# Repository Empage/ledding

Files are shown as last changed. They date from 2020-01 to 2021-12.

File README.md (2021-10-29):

Ledding
=======

Fancy LED project

<!-- vim-markdown-toc GFM -->

* [Hardware](#hardware)
    * [LED stripe WS2812B and WS2815](#led-stripe-ws2812b-and-ws2815)
        * [Timing:](#timing)
    * [Power considerations](#power-considerations)
        * [WS2812B](#ws2812b)
        * [WS2815](#ws2815)
        * [Cabling](#cabling)
    * [Level shifters](#level-shifters)
* [Software](#software)
    * [Installation](#installation)
    * [Important commands](#important-commands)
    * [Programming](#programming)
    * [Debugging using JTAG](#debugging-using-jtag)
        * [Make the physical connection](#make-the-physical-connection)
        * [One time setup configuration](#one-time-setup-configuration)
        * [Start a debugging session](#start-a-debugging-session)
* [Specifics for Partyraum Installation](#specifics-for-partyraum-installation)
    * [I/O](#io)
* [Specifics for Maite Installation](#specifics-for-maite-installation)
    * [Box interfaces](#box-interfaces)
    * [Buttons](#buttons)
* [TODO](#todo)
* [Lessons learned](#lessons-learned)

<!-- vim-markdown-toc -->

## Hardware
1. MCU is the ESP32

Feature | Description
---------- | ------
SoM | from Broodio (quite unknown, selecting the ESP32 Development Kit (DevKitC) is suitable)
SoC | ESP-WROOM-32D
CPU | ESP32-D0WD
Flash | 4 MiB
RAM | 320 KiB

1. LED stripes are WS2812B and WS2815 with 30 LEDs per meter and WS2812B with 60 LEDs per meter.

### LED stripe WS2812B and WS2815
Consists of a 5050 SMD and a WS2812B or WS2815 chip.

#### Timing:
Clock of the stripe is at 800 kHz. Writing one bit takes
```
t_b = 1 / 800 kHz = 1.25 µs
```
Writing one pixel takes
```
t_B = 24 bit * 1.25 µs/bit = 30 µs`
```
Writing 10m stripe of 30 LED/m takes
```
T = 10 m * 30 px/m * 30 µs = 9 ms
```
This would give a maximum refresh rate of
```
f = 1 / 9 ms ≈ 111 Hz
```

### Power considerations
#### WS2812B
For the 5V strips each LED pulls max. ~20 mA (realistic max is 15 mA) per color, so 60 mA (45 mA) per pixel.
For 10 m of the 30 px/m stripe, we have at maximum brightness
```
Theoretical:
I_t5 = 10 m * 30 px/m * 60 mA/px = 18 A
P_t5 = 18 A * 5V = 90 W

Realistic:
I_r5 = 10 m * 30 px/m * 45 mA/px = 13.5 A
P_r5 = 13.5 A * 5V = 67.5 W
```

#### WS2815
For the 12V strips each LED pulls max. 15 mA per color, but also max. 15 mA for the full pixel (they are in series). Power is burnt for non-white.
For 10 m of the 30 LED/m stripe, we have at maximum brightness
```
I_r12 = 10 m * 30 px/m * 15 mA/px = 4.5 A
P_r12 = 15 A * 12V = 54 W
```

#### Cabling
For the cable the resistance is
```
R = l / (\kappa * A)
```
where l is the cable length in m, kappa is the conductivity in (m / (\ohm * mm^2)) and A is the cross-section in mm^2.
Longest length is 18 m (twice that to account for GND back) with copper `\gamma = 57.18 (m / (\ohm * mm^2))`
```
R_2.5 = 36 m / 57.18 (m / (\ohm * mm^2)) / 2.5 mm^2 ≈ 0.252 \Ohm
R_1.5 = 36 m / 57.18 (m / (\ohm * mm^2)) / 1.5 mm^2 ≈ 0.420 \Ohm
```
Assuming to power 5 m of the LED strip with the 18m of cable leads to
```
I = 5 m * 30 px/m * 45 mA = 6.75 A
U = 0.252 * 6.75 A = 1.701 V
```
leaving only `5 - 1.701 = 3.299 V` for the LEDs with 2.5 mm^2 copper cable. Not really enough...\
With the WS2815 it would be:
```
I = 5 m * 30px/m * 15 mA = 2.25 A
U_c2.5 = 0.252 * 2.25 A = 0.567 V for 2.5 mm^2 copper or
U_c1.5 = 0.420 * 2.25 A = 0.945 V for 1.5 mm^2 copper
```
leaving > 11 V for the LEDs in both cases. This should enough for equal color rendering on all LEDs (to be confirmed).

### Level shifters
Available (should be fast enough):
- 74AHCT125 (quad level shifter)
- TXB0108 (eight channel bi-directional)

## Software
### Installation
This project uses platformio (https://platformio.org/) as its build system.
To install platformio, download and execute the `get-plaformio.py` script
```
wget https://raw.githubusercontent.com/platformio/platformio-core-installer/master/get-platformio.py -O get-platformio.py
python3 get-platformio.py
```

Install dependencies with pio:

```
pio lib install "FastLED"
```

To be able to upload, the user needs to be able to open the USB device, thus being in the `dialout` group
```
sudo usermod -aG dialout <user>
```

### Important commands
Important platformio commands (next to those in the Makefile which are described there):

Start serial console:
```
pio device monitor -b 115200
```

Generate `compile_commands.json`:
```
platformio run --target compiledb
mv .pio/build/ota/compile_commands.json .
```

### Programming
Important configuration is passed via environment variables (such as WLAN_SSID, PSK and IPs).
To work with a specific enviroment, we can source the relevant enviroment:
```
source env-partyraum
```
After that, we can use the Makefile targets for programming:
- To program the ESP32 via USB cable, issue `make upload`, then hold down the `BOOT` button on the ESP32-board until the upload starts.
- For OTA programming, issue `make ota`

The `env-partyraum` is the default environment and doesn't need to be sourced, but we can use this file to create custom
environments such as `env-maite` or `env-testbed` (not commited due to secret WLAN PSK).

### Debugging using JTAG
On-target debugging with GDB is possible using JTAG. I have the `FT4232H-56Q MiniModule` as the USB2JTAG adapter. The following steps are necessary:

#### Make the physical connection
| JTAG function | ESP32 pin | FT4232H pin |
| --- | --- | --- |
| TDI (Test Data In) | GPIO12 | AD1 |
| TDO (Test Data Out) | GPIO15 | AD2 |
| TCK (Test Clock) | GPIO13 | AD0 |
| TMS (Test Mode Select) | GPIO14 | AD3 |
| TRST (Test Reset) | EN | RT# |
| GND | GND | GND |

Furthermore the jumpers on the MiniModule need to be set to provide the reference voltage.

#### One time setup configuration
This module is not recognized correctly by `OpenOCD` (Open On-Chip-Debugger) used by `platformio` which is why
we need to tell it. Connect the MiniModule to USB and get the description and IDs:
```
$ pio device list

/dev/ttyUSB3
------------
Hardware ID: USB VID:PID=0403:6011 SER=FT2AWE2C LOCATION=1-5:1.3
Description: FT4232H-56Q MiniModule

/dev/ttyUSB2
------------
Hardware ID: USB VID:PID=0403:6011 SER=FT2AWE2C LOCATION=1-5:1.2
Description: FT4232H-56Q MiniModule

/dev/ttyUSB1
------------
Hardware ID: USB VID:PID=0403:6011 SER=FT2AWE2C LOCATION=1-5:1.1
Description: FT4232H-56Q MiniModule

/dev/ttyUSB0
------------
Hardware ID: USB VID:PID=0403:6011 SER=FT2AWE2C LOCATION=1-5:1.0
Description: FT4232H-56Q MiniModule
```

For this module, we need to add (or change the existing values) in `~/.platformio/packages/tool-openocd-esp32/share/openocd/scripts/interface/ftdi/minimodule.cfg`
Add or change the following:
```
ftdi_device_desc "FT4232H-56Q MiniModule"
ftdi_vid_pid 0x0403 0x6011
```

This should eliminate the following errors on a debug run
```
$ pio debug --interface gdb -x .pioinit

[...]
Error: no device found
Error: unable to open ftdi device with vid 0403, pid 6011, description 'FT2232H MiniModule', serial '*' at bus location '*'
```

This is valid for the `debug_tool = minimodule` (see `platformio.ini`).
We would only need to repeat those steps if the `platformio` update replaced this files with the originals again.

#### Start a debugging session
**Potential pitfall first**:
The GPIOs for JTAG (12 - 15) are also used for touch buttons. When they are actually used for this functionality,
the debugger cannot initiate the debugging session.
TODO add error msg here

That's why we must flash a firmware not using those buttons first using the normal flashing mechanisms. It can basically be any firmware because during beginning of the JTAG session the firmware to be debugged will be loaded anyway.

Building a debug version of the firmware will define `DEBUG_JTAG` and hence not use those touch buttons, so `make debug` will work.

To actually start a debugging session with GDB, use
```
pio debug --interface gdb -x .pioinit
```

## Specifics for Partyraum Installation
LED stripes of
- 2x 10 m
- 4x  2 m

results in `28 m * 30 px/m = 840 px`. Safety margin: `900 px`

We choose the WS2815 for less current and therefore easier cabeling
Theoretically, we need
```
900 px * 15 mA/px = 13.5 A
13.5 A * 12 V = 162 W
```

The Meanwell LRS-200-12 is a good fit.

### I/O

- Button 1: Brightness
- Button 2: Mode
- Button 3: Color
- Button 4: Intensity
- LED 1: WiFi connected?
- LED 2: Serial data from Raspberry Pi received last second
- LED 3: TODO
- LED 4: TODO

## Specifics for Maite Installation
LED stripes WS2812B
```
5 m * 30 px/m = 150 px
```
Power consumption (realistic maximum)
```
I_r5 = 5 m * 30 px/m * 45 mA/px = 6.75 A
P_r5 = 6.75 A * 5V = 33.75 W
```

Cable is J-Y(ST)Y:
```
R_0.6 = 12 m / 57.18 (m / (\ohm * mm^2)) / 0.6 mm^2 ≈ 0.350 \Ohm
R_1.2 = 12 m / 57.18 (m / (\ohm * mm^2)) / 1.2 mm^2 ≈ 0.175 \Ohm
```
Assuming to power half of the LED strip:
```
I = 2.5 m * 30 px/m * 45 mA = 3.375 A
U_0.6 = 0.350 * 3.375 A = 1.181 V
U_1.2 = 0.175 * 3.375 A = 0.591 V
```

### Box interfaces
- Power Input
- µUSB
- Led OUT 5-port:
    - Data
    - GND front
    - VCC front
    - GND back
    - VCC back
- Status LED
- 3 Buttons
- Power switch
- 2 Potis for speed and brightness

### Buttons
1. Brightness +
2. Brightness -
3. Speed +
4. Speed -
5. Color next
6. Color prev
7. Mode next
8. Mode prev

## TODO
1. Add schematics
    1. Add a RPI connection to the `BOOT` button to be able to flash without manual interaction
1. Use ESP Log functions instead of serial directly for more finegrained logging

## Lessons learned
1. When creating a new environment in `platformio.ini`, one needs to reinstall the dependency libraries

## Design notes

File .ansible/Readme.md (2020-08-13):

This is design for the use on the raspberry, but it can be used from remote machines aswell.
All you have to do would be editing the hosts-file.

Use "make build" for installing prerequisite.

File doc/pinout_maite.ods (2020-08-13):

 |  | ESP32
Case Plug |  | Antenna
5V |  | EN | GPIO23 | B1 Level Shifter (Stripe Data)
GND |  | GPIO36 | GPIO22
Status LED |  | GPIO39 | GPIO1
Stripe Data |  | GPIO34 | GPIO3
 |  | GPIO35 | GPIO21
 | T9: Color next | GPIO32 | GPIO19
 | T8: Color prev | GPIO33 | GPIO18 | DevButton
 |  | GPIO25 | GPIO5
 |  | GPIO26 | GPIO17
 | T7: Brightness - | GPIO27 | GPIO16
 | T6: Brightness + | GPIO14 | GPIO4 | T0: Mode prev
 | T5: Intensity - | GPIO12 | GPIO2 | Internal Blue LED
 | T4: Intensity + | GPIO13 | GPIO15 | T3: Mode next
 |  | GND | GND
 | 5V | VIN | 3V3
 |  | USB
 |  | SN74HCT245
 |  | Notch
 | GND | DIR | Vcc | 5V
 | Stripe Data | A1 | OE | GND
 |  | A2 | B1 | GPIO23
 |  | A3 | B2
 |  | A4 | B3
 |  | A5 | B4
 |  | A6 | B5
 |  | A7 | B6
 |  | A8 | B7
 | GND | GND | B8
 |  | Button Layout
 |  | Brightness + | Mode next | Color next | Intensity +
 |  | Brightness - | Mode prev | Color prev | Intensity -

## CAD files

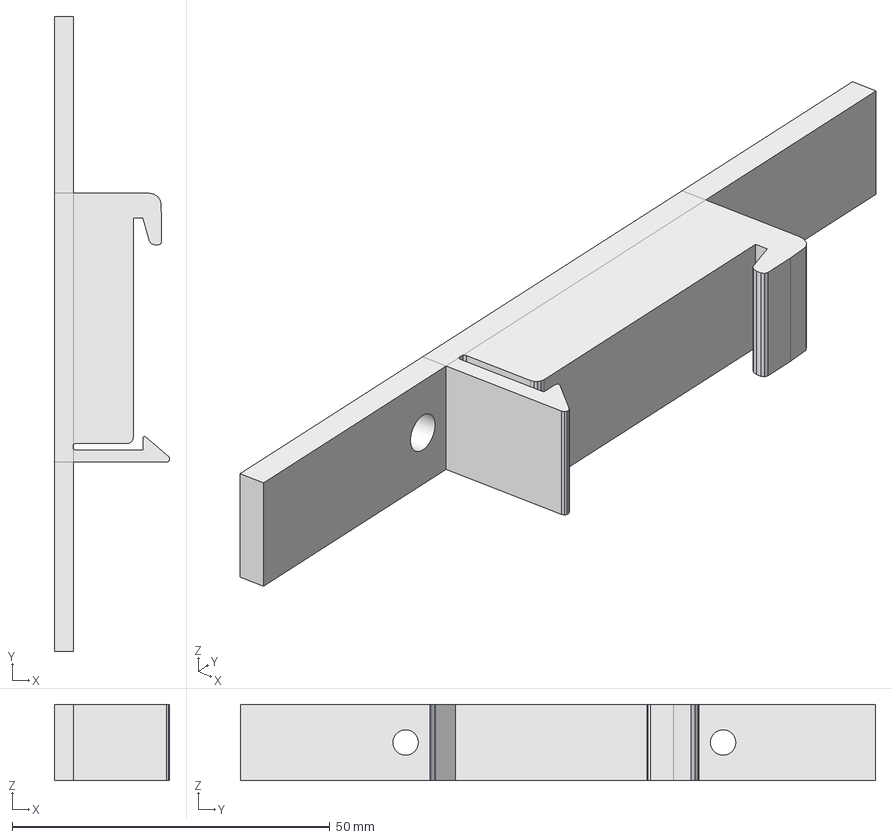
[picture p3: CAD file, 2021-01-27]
doc/3dprinting/dinrail_mw_lrs200.FCStd
18.2 x 100.0 x 12.0 mm

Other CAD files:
doc/3dprinting/dinrail_mw_lrs200.stl

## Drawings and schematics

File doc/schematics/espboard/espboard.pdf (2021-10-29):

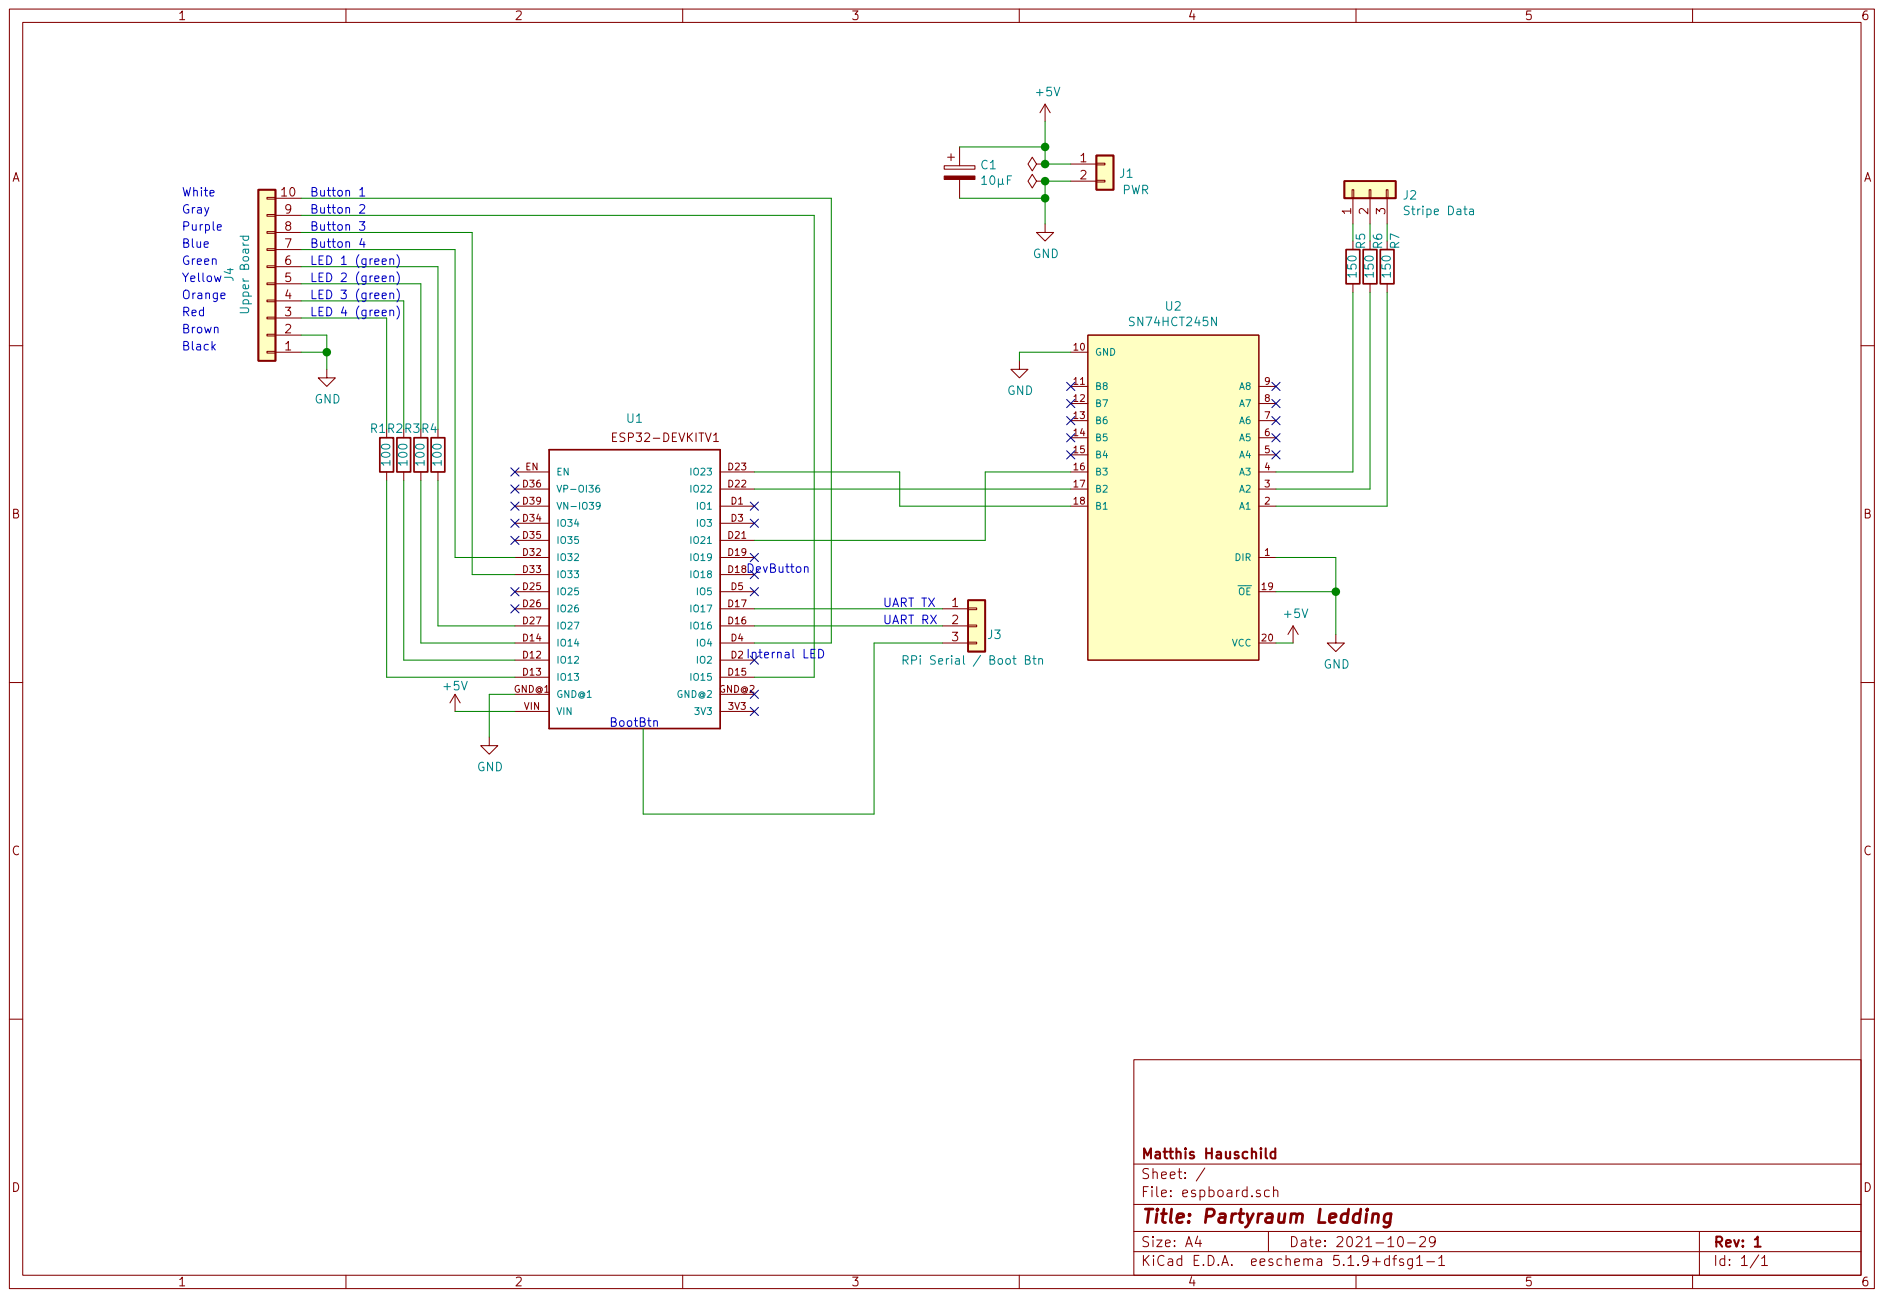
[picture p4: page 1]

LED 3 (green) Button 3 Button 4

File: espboard.sch Sheet: / Matthis Hauschild

Id: 1/1 Title: Partyraum Ledding

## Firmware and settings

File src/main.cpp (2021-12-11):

/* Ledding - a fancy LED project */

#include <Arduino.h>
#include <FastLED.h>
#include <config.h>

/* include global instances of leds, animator, buttons, ota and effects */
#include "globals.h"

void setupMaite() {
	animator.mode = Animator::ANIMATOR_CONSTANT;
}

void setupThias() {
	animator.mode = Animator::ANIMATOR_CONSTANT;
}

#ifdef CONF_PARTYRAUM
void setupPartyraum() {
	/* setup connection to RPi */
    Serial2.begin(115200, SERIAL_8N1, SERIAL_TO_RPI_RXD2, SERIAL_TO_RPI_TXD2);

	/* setup partyraum specifc effects */
	arcEffect.configure(CRGB::Blue, CRGB::Green);
	animator.addEffect(Animator::ANIMATOR_ARC, &arcEffect);
	soundEffect.configure(CRGB::Red);
	animator.addEffect(Animator::ANIMATOR_SOUND, &soundEffect);

	animator.mode = Animator::ANIMATOR_SOUND;

	pinMode(STATUS_LED_1, OUTPUT);
	pinMode(STATUS_LED_2, OUTPUT);
	pinMode(STATUS_LED_3, OUTPUT);
	pinMode(STATUS_LED_4, OUTPUT);

	digitalWrite(STATUS_LED_1, LOW);
	digitalWrite(STATUS_LED_2, LOW);
	digitalWrite(STATUS_LED_3, LOW);
	digitalWrite(STATUS_LED_4, LOW);
}
#endif /* CONF_PARTYRAUM */

void setup() {
	FastLED.addLeds<WS2812B, LED_DATA_PIN, GRB>(leds, NUM_LEDS);
	FastLED.addLeds<WS2812B, LED_DATA_PIN2, GRB>(leds + NUM_LEDS, NUM_LEDS);
	FastLED.setBrightness(DEF_GLOBAL_BRIGHTNESS);
	FastLED.setDither();
    fill_solid(leds, NUM_LEDS, CRGB::Black);
    fill_solid(leds + NUM_LEDS, NUM_LEDS, CRGB::Red);
    FastLED.show();

	pinMode(BUILTIN_LED, OUTPUT);

#ifdef SERIAL_PRINT
	Serial.begin(115200);
#endif

	/* setup common effects */
	staticEffect.configure(CRGB::DeepPink);
	animator.addEffect(Animator::ANIMATOR_CONSTANT, &staticEffect);
	boltEffect.configure(0, 2, CRGB::Red, 10);
	animator.addEffect(Animator::ANIMATOR_BOLT, &boltEffect);
	strobeEffect.configure(CRGB::White);//, 3, 50, 1000);
	animator.addEffect(Animator::ANIMATOR_STROBE, &strobeEffect);
	sparkleEffect.configure(CRGB::White, true);
	animator.addEffect(Animator::ANIMATOR_SPARKLE, &sparkleEffect);
	meteorEffect.configure(CRGB::Blue);
	animator.addEffect(Animator::ANIMATOR_METEOR, &meteorEffect);

	/* setup specifics for individual installation */
#ifdef CONF_MAITE
	setupMaite();
#elif CONF_THIAS
	setupThias();
#elif CONF_PARTYRAUM
	setupPartyraum();
#endif

#ifdef DEV_MODE
	/* turn on builtin LED */
	digitalWrite(BUILTIN_LED, HIGH);
#endif

	ota.init();
}


void loop() {
	ota.handleOta();

	EVERY_N_MILLISECONDS(REDRAW_RESOLUTION) {
		animator.redraw();
	}

	EVERY_N_MILLISECONDS(BUTTON_CHECK_RES) {
		buttons.handleButtons();
	}
}

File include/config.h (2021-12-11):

#ifndef CONFIG_H
#define CONFIG_H

#include <IPAddress.h>
#include <FastLED.h>

/*! Configuration of the project
 *
 * All config parameters which are defined extern are located in `config.cpp`
 */

/*************************/
/* dynamic configuration */
/*************************/
/*! \brief Print all actions on serial */
#define SERIAL_PRINT

/*! \brief Activate developing mode, currently
 * - extra button on dev board
 */
#define DEV_MODE
#define DEV_BUTTON_PIN 18


/***********************************/
/* static configuration for all HW */
/***********************************/

/* WiFi and OTA settings set in config.cpp */
extern const char* SSID;
extern const char* WIFI_PSK;
extern const char* OTA_PW;

/* for pin configuration, please check doc/pinout_maite.ods */
/*! \brief GPIO on which the data signal of the WS2812B is connected */
#define LED_DATA_PIN 23
#define LED_DATA_PIN2 22

/*! \brief GPIO for the built-in LED */
#define BUILTIN_LED 2

/*! \brief How often are the button states polled in ms */
#define BUTTON_CHECK_RES 100

/*! \brief Resolution of the stripe redrawing routine (i.e. the delay each round) in ms */
#define REDRAW_RESOLUTION 10

/*! \brief Default global brightness to start with */
#define DEF_GLOBAL_BRIGHTNESS 200

extern const IPAddress OWN_IP_ADDRESS;
extern const IPAddress SUBNET;

extern const uint16_t OTA_PORT;

/*! \brief These colors are choseable by button */
extern const CRGB::HTMLColorCode COLOR_PALETTE[];
extern const int COLOR_PALETTE_SIZE;

/* tmp */
#define MIC_PIN 13
#define DC_OFFSET 0
#define SQUELCH 0



/******************************************/
/* static configuration for individual HW */
/******************************************/
#ifdef CONF_MAITE
	/*! \brief Total number of LEDs */
	#define NUM_LEDS 150
	#define HAS_TOUCHBUTTONS

#elif CONF_THIAS
	/*! \brief Total number of LEDs */
	#define NUM_LEDS 120
	#define HAS_TOUCHBUTTONS

#elif CONF_MATTHIS
	/*! \brief Total number of LEDs */
	#define NUM_LEDS 150

#elif CONF_PARTYRAUM
	/*! \brief Total number of LEDs */
	#define NUM_LEDS 480
	#define HAS_PD_BUTTONS

	/*! \brief Serial input from RPi (LED data) */
	#define SERIAL_TO_RPI_RXD2 17
	/*! \brief Serial output to RPi (ACKs for LED data input) */
	#define SERIAL_TO_RPI_TXD2 16

	#define STATUS_LED_1 27
	#define STATUS_LED_2 13
	#define STATUS_LED_3 12
	#define STATUS_LED_4 14

#else
	#error "Please define the HW for which to build"
#endif


#ifdef HAS_TOUCHBUTTONS
/*! \brief Touch button definitions
 *
 * Layout on Maites & Thias version:
 * BRT_INC   MODE_NEXT   COLOR_NEXT   INTENSITY_INC
 * BRT_DEC   MODE_NEXT   COLOR_PREV   INTENSITY_DEC
 *
 * If using JTAG, one cannot use the GPIOs linked to that for touch (12 - 15).
 * This will be handled in the Buttons class, here we only need to change the button count
 */
#ifdef DEBUG_JTAG
	#define TOUCH_BUTTON_COUNT    4
#else
	#define TOUCH_BUTTON_COUNT    8
#endif

#define BUTTON_BRT_INC       14
#define BUTTON_BRT_DEC       27
#define BUTTON_MODE_NEXT     15
#define BUTTON_MODE_PREV      4
#define BUTTON_COLOR_NEXT    33 /* this should be GPIO32 */
#define BUTTON_COLOR_PREV    32 /* this should be GPIO33, dont know where the mixup is */
#define BUTTON_INTENSITY_INC 13
#define BUTTON_INTENSITY_DEC 12

/*! \brief Threshold value of the touch button
 *
 * This is highly depenend on the concrete realization and should be tested in each device
 * If the actual value which was read was below this twice in a row, the button is considered pressed.
 * Twice because there a some occasional bogus reads below the threshold although it was not pressed.
 */
#define TOUCH_BUTTON_THRESHOLD 30

#endif /* HAS_TOUCHBUTTONS */

#ifdef HAS_PD_BUTTONS
	#define PD_BUTTON_COUNT       4

	#define BUTTON_BRT_INC        4
	#define BUTTON_MODE_NEXT     15
	#define BUTTON_COLOR_NEXT    33
	#define BUTTON_INTENSITY_INC 32
#endif  /* HAS_PD_BUTTONS */

#endif /* end of include guard: CONFIG_H */

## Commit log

2020-01-06 Initialized the project
    Using `platformio init --ide vim --board esp32dev`
2020-05-16 Add some theory and datasheets
    [price_analysis.ods]
2020-07-29 Make a first test version practical with:
    - touch buttons
    - ArduinoOTA
    - event based system
    [pinout_maite.ods]
2020-08-13 adjust pins and leds
2020-08-13 rework main file for arduino
    [main.cpp]
2020-08-13 auto fill missing leds
    [pyaudio-testing.py]
2020-08-13 Add bolt and arc effects, first versions
    [pinout_maite.ods]
2020-08-22 Reorganization and add switch for Maite and partyraum
2020-08-22 Higher TOUCH THRESHOLD value, fix merge bugs
    [config.h, effect.cpp]
2020-08-26 Introduce environments for the different LED installations
    Such as partyraum, maite or testbed
2020-08-26 Change DEV_BUTTON to mode switch
2020-08-26 wip: bolt and sparkle
2020-10-04 first esp32 schematics ready
    [espboard.kicad_pcb, espboard.sch]
2020-12-30 Add 3d printed dinrail clip for the MW power supply
    [dinrail_mw_lrs200.FCStd, dinrail_mw_lrs200.stl]
2020-12-30 Updated schematics
    [espboard.sch]
2021-01-27 Lowered hight of dinrail clips
    for better airflow in the casing
    [dinrail_mw_lrs200.FCStd, dinrail_mw_lrs200.stl]
2021-01-27 Continued schematics
    - changed LED resistors to 100 Ohm
    - use green leds
    - changed stripe data resistors to 150 Ohm
    - 10 µF capacitor power buffer
    - Boot button exposed to RPi pin header
    [espboard.sch]
2021-02-13 Add cable env for "normal" upload target
2021-02-14 Move schematics library one up for the other schematics to use
2021-02-14 Start empty schematics thiasmaite
    [thiasmaite.kicad_pcb, thiasmaite.sch]
2021-02-15 Added whole schematics from Maite board
    [thiasmaite.sch]
2021-02-15 Changed connector positions and added pin description
    [thiasmaite.sch]
2021-02-15 Added case schematics, finished whole schematics
    [thiasmaite.sch]
2021-02-21 Partyraum schematics: add cable colors for connector
    [espboard.sch]
2021-02-22 Partyraum schematics: Changed pinning for easier layout on perfboard
    [espboard.sch]
2021-05-01 Add Thias LED stripe
2021-10-29 Add new partyraum HW with extra buttons
    working version, but buttons class is not very nice right now. Maybe
    split touch and pulldown buttons into separate classes?
2022-10-03 tmp: esp restart button
2026-04-18 wip: currently working with PI 115200
